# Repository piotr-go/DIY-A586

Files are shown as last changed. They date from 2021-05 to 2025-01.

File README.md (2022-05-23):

# DIY-A586 by Piotr Gozdur <piotr_go>
© COMMERCIAL USE NOT ALLOWED!

- [DIY-A586 v1.6](./v1.6)
(8MB RAM)
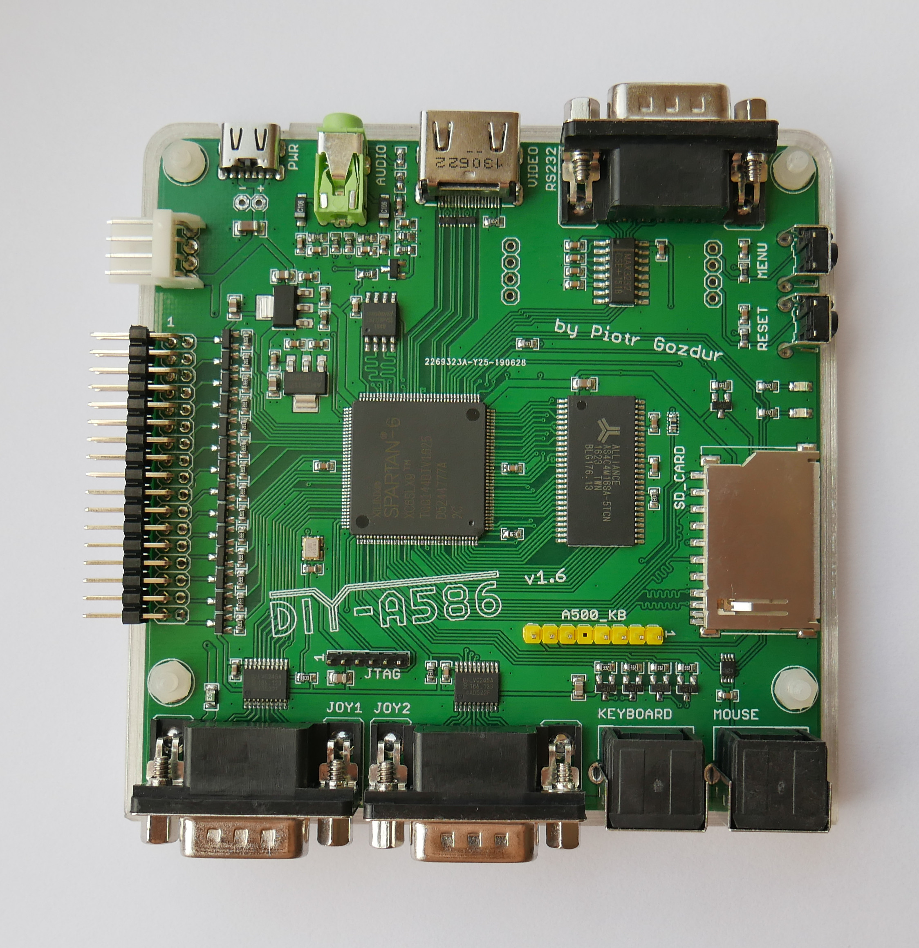
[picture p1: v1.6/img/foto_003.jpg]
DIY-A586 v1.6


- [DIY-A586 v1.9](./v1.9)
(32MB RAM)
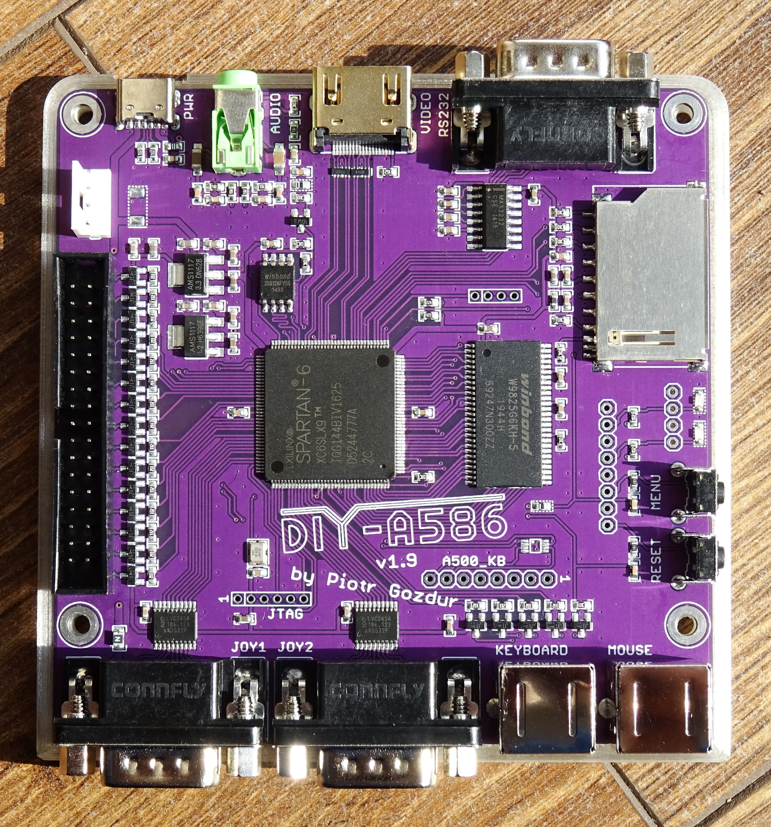
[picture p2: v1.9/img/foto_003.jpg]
DIY-A586 v1.9


<br><b>If you like my projects, you can support me with a donation.&nbsp;&nbsp;</b>

<b>&nbsp;&nbsp;Thank you.</b><br>

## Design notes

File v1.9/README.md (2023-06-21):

# DIY-A586 v1.9 by Piotr Gozdur <piotr_go>
© COMMERCIAL USE NOT ALLOWED!

<!-- no toc -->
- [Board](#board)
- [Schematic](#schematic)
- [Main menu](#main-menu)
- [Available cores](#available-cores)
- [Initial flashing of the firmware](#initial-flashing-of-the-firmware)
  - [Using CH341A 24 25 Series EEPROM Flasher](#using-ch341a-24-25-series-eeprom-flasher)
  - [detailed example of how to flash](#detailed-example-of-how-to-flash)
- [Links](#links)

## Board
[Gerber files](pcb/v1.9/gerbers.tar.gz) and [main core](main/MAIN%20v0.4.4a.tar.gz) included.

DIY-A586 top
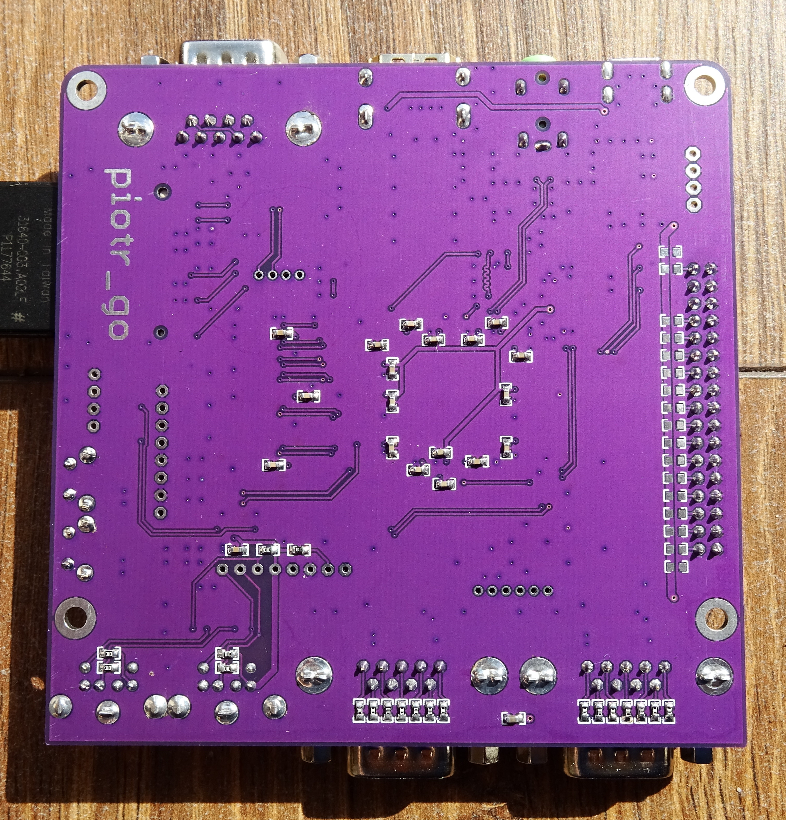
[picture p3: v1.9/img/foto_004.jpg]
DIY-A586 bottom


## Schematic
Schematic

## Main menu
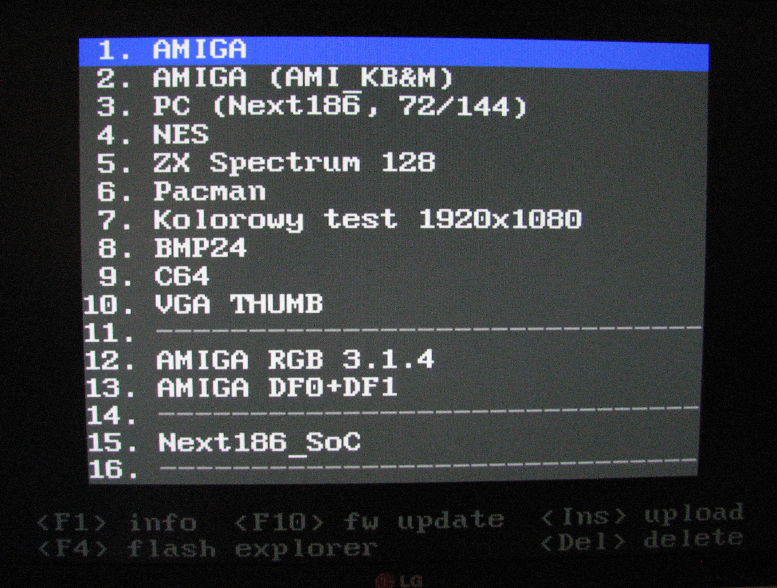
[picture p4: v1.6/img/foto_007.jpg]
main-menu


## Available cores
* Amiga (Minimig)
* PC 8088
* NES
* RISC-V

## Initial flashing of the firmware

### Using CH341A 24 25 Series EEPROM Flasher

This shows the initial flashing with the CH341A programmer on Ubuntu using the [flashrom tool](https://manpages.ubuntu.com/manpages/focal/man8/flashrom.8.html).

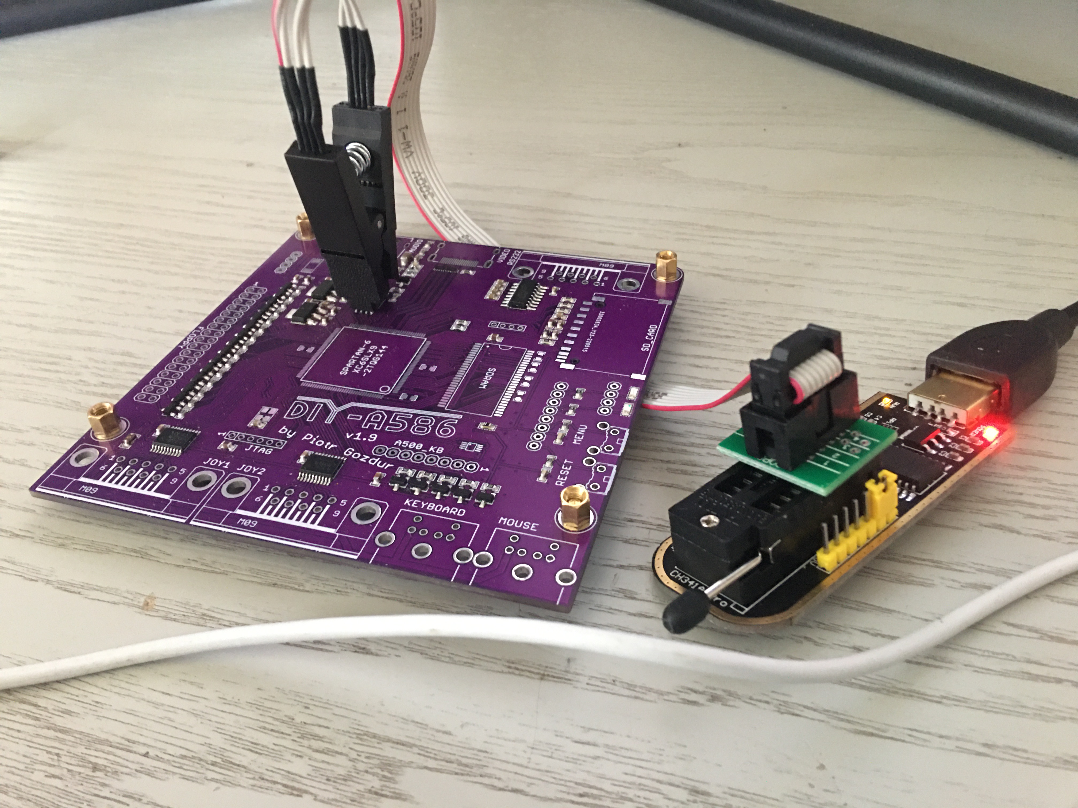
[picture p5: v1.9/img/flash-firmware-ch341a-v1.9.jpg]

flashrom has the weird behaviour that the bin file must have the exact size of the flash rom. This can be fixed with the following workaround:

* read empty flash and write to local .bin file: ```sudo flashrom --programmer ch341a_spi -r example.bin```
* copy main.bin into example.bin with: ```dd if=main.bin of=example.bin conv=notrunc```
* check result: ```vbindiff main.bin example.bin```

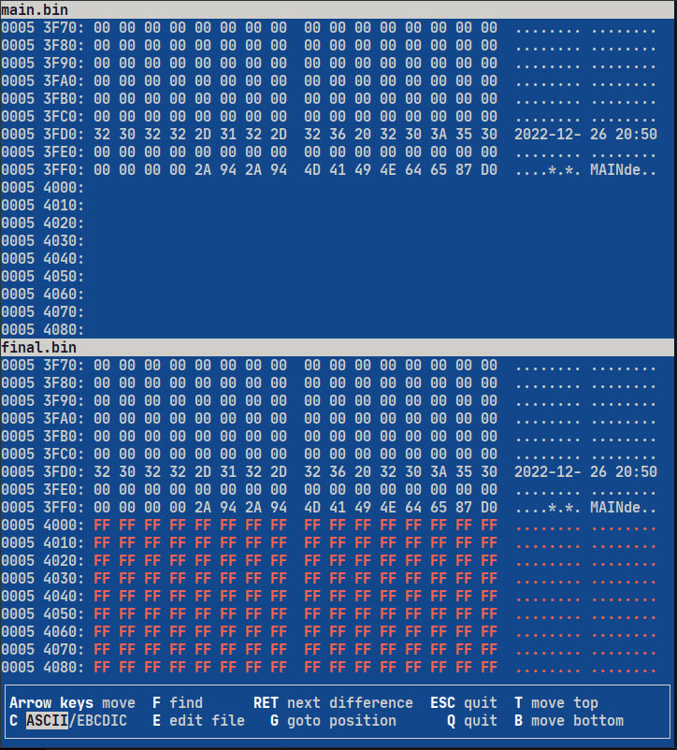
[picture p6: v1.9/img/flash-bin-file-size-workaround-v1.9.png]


* now you have a bin file with correct size to flash: ```sudo flashrom --programmer ch341a_spi -w example.bin```
* you're done ;o)

> Change the example filenames above to your needs respectively to current main.bin version!

### detailed example of how to flash

```bash
# read the contents of current soldered empty flash memory
csg@csg-deskmini-300:~/git/DIY-A586/v1.9/main$ sudo flashrom --programmer ch341a_spi -r empty.bin
[sudo] Passwort für csg: 
flashrom v1.2 on Linux 5.15.0-73-generic (x86_64)
flashrom is free software, get the source code at https://flashrom.org

Using clock_gettime for delay loops (clk_id: 1, resolution: 1ns).
Found Winbond flash chip "W25Q128.V" (16384 kB, SPI) on ch341a_spi.
Reading flash... done.

# make copy of empty rom file
csg@csg-deskmini-300:~/git/DIY-A586/v1.9/main$ cp empty.bin final.bin

# copy main.bin into final.bin rom file
csg@csg-deskmini-300:~/git/DIY-A586/v1.9/main$ dd if=main.bin of=final.bin conv=notrunc
672+0 Datensätze ein
672+0 Datensätze aus
344064 Bytes (344 kB, 336 KiB) kopiert, 0,00142343 s, 242 MB/s

# use vbindiff to show result of dd command. see screenshot above.
csg@csg-deskmini-300:~/git/DIY-A586/v1.9/main$ vbindiff main.bin final.bin 
VBinDiff 3.0_beta5, Copyright 1995-2017 Christopher J. Madsen
VBinDiff comes with ABSOLUTELY NO WARRANTY; for details type 'vbindiff -L'.

# write final.bin file to rom
csg@csg-deskmini-300:~/git/DIY-A586/v1.9/main$ sudo flashrom --programmer ch341a_spi -w final.bin 
flashrom v1.2 on Linux 5.15.0-73-generic (x86_64)
flashrom is free software, get the source code at https://flashrom.org

Using clock_gettime for delay loops (clk_id: 1, resolution: 1ns).
Found Winbond flash chip "W25Q128.V" (16384 kB, SPI) on ch341a_spi.
Reading old flash chip contents... done.
Erasing and writing flash chip... Erase/write done.
Verifying flash... VERIFIED.

# optional: verify again if wanted.
csg@csg-deskmini-300:~/git/DIY-A586/v1.9/main$ sudo flashrom --programmer ch341a_spi -v final.bin 
flashrom v1.2 on Linux 5.15.0-73-generic (x86_64)
flashrom is free software, get the source code at https://flashrom.org

Using clock_gettime for delay loops (clk_id: 1, resolution: 1ns).
Found Winbond flash chip "W25Q128.V" (16384 kB, SPI) on ch341a_spi.
Verifying flash... VERIFIED.
```

## Links
* https://www.elektroda.pl/rtvforum/topic3891155.html
* https://youtu.be/KzVHhvZciVI

<br><b>If you like my projects, you can support me with a donation.&nbsp;&nbsp;</b>

<b>&nbsp;&nbsp;Thank you.</b><br>

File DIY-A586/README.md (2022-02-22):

# DIY-A586 by Piotr Gozdur <piotr_go>

- [Board](#board)
- [Schematic](#schematic)
- [Menu of main core](#menu-of-main-core)
- [Available cores](#available-cores)
- [Running Minimig core](#running-minimig-core)
- [Initial flashing of the firmware](#initial-flashing-of-the-firmware)
  - [Using CH341A 24 25 Series EEPROM Flasher](#using-ch341a-24-25-series-eeprom-flasher)
- [Gotek Floppy Emulator](#gotek-floppy-emulator)
- [Floppy splitter](#floppy-splitter)
  - [Floppy splitter board](#floppy-splitter-board)
  - [Floppy splitter schematic](#floppy-splitter-schematic)
  - [Programming the PIC16F15313](#programming-the-pic16f15313)
  - [Pinout PIC16F15313](#pinout-diagram-pic16f15313)
  - [Pinout PICkit3](#pinout-pickit3)
- [Links](#links)

## Board

[Gerber files](pcb/v1.6/gerbers.tar.gz) and [main core](main/MAIN%20v0.4.3.tar.gz) included.

> © DIY-A586 by Piotr Gozdur. COMMERCIAL USE NOT ALLOWED!

DIY-A586 top
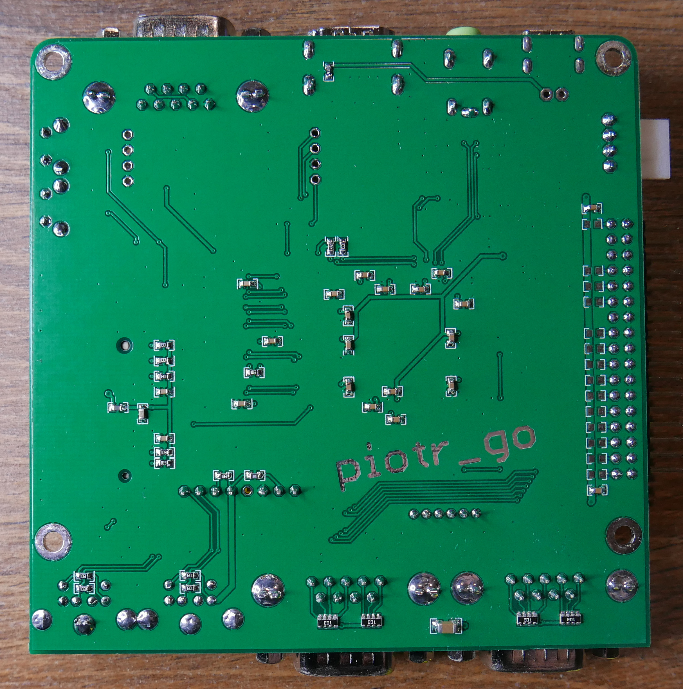
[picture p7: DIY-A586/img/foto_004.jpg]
DIY-A586 bottom


## Schematic
Schematic

## Menu of main core
Main core menu

## Available cores

* Amiga (Minimig)
* NES
* Next186 SoC PC
* RISC-V
* Sinclair Spectrum

## Running Minimig core
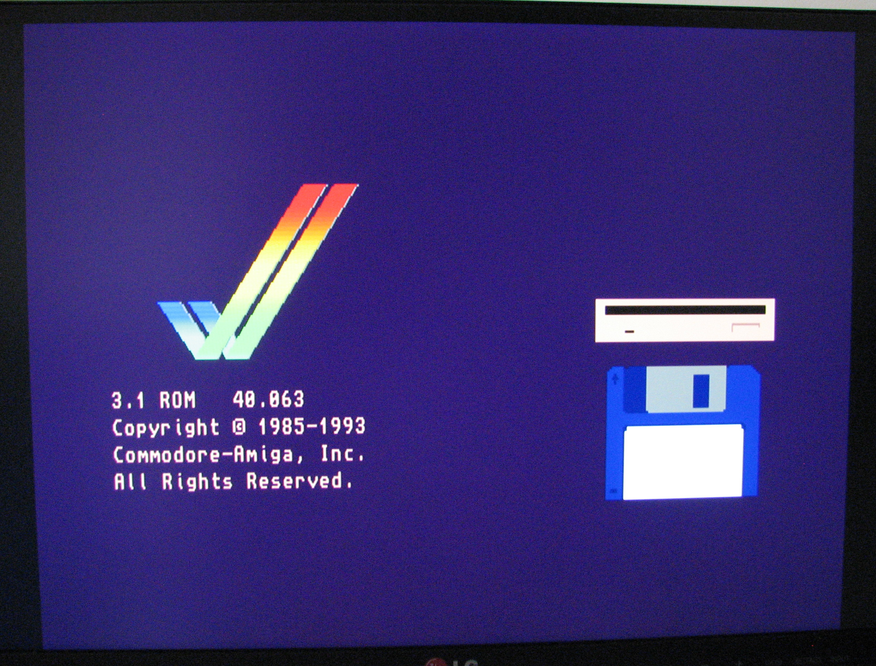
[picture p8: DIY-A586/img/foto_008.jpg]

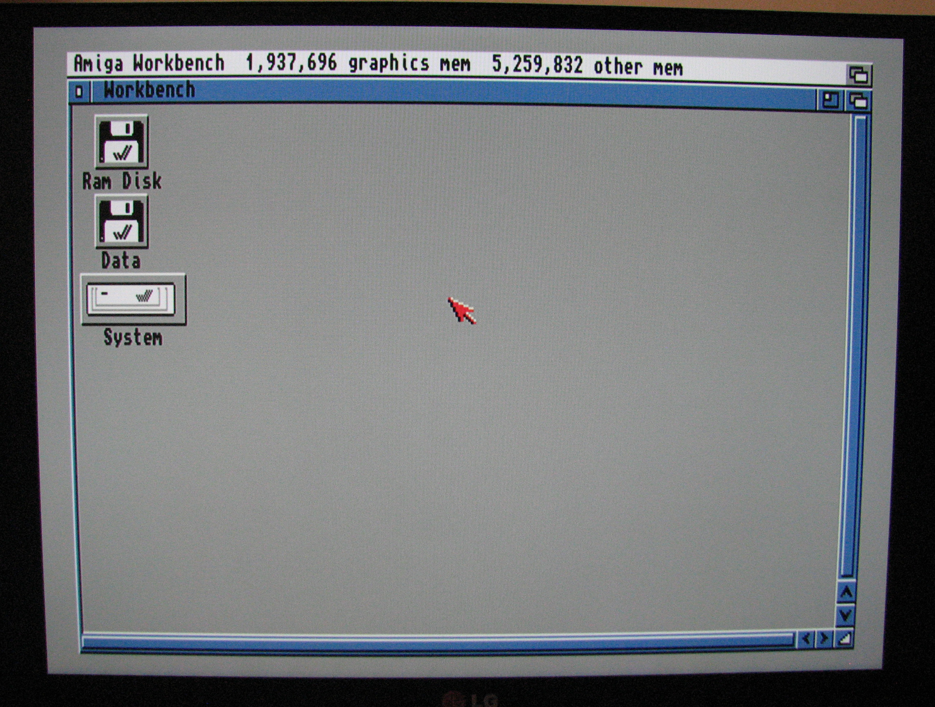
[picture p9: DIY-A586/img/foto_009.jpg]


## Initial flashing of the firmware

### Using CH341A 24 25 Series EEPROM Flasher

This shows the initial flashing with the CH341A programmer on Ubuntu using the [flashrom tool](https://manpages.ubuntu.com/manpages/focal/man8/flashrom.8.html).

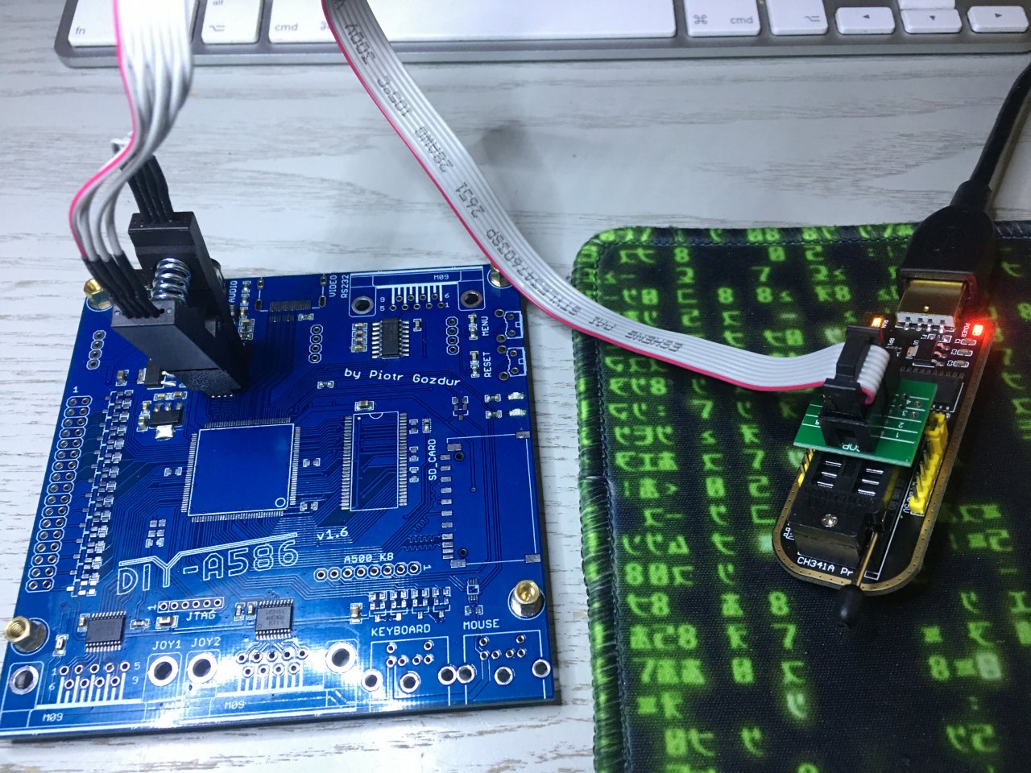
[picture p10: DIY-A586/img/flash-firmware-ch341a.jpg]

flashrom has the weird behaviour that the bin file must have the exact size of the flash rom. This can be fixed with the following workaround:

* read empty flash and write to local .bin file: ```sudo flashrom --programmer ch341a_spi -r example.bin```
* copy main.bin into example.bin with: ```dd if=main.bin of=example.bin conv=notrunc```
* check result: ```vbindiff main.bin example.bin```

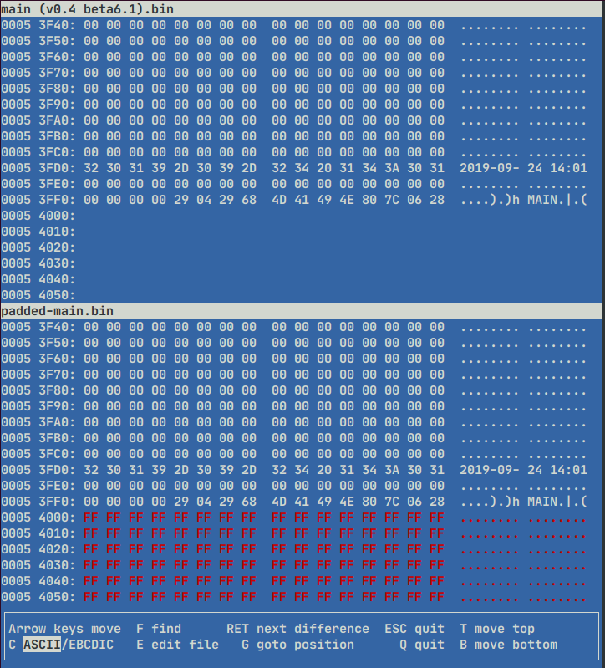
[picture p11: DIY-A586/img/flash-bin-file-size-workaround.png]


* now you have a bin file with correct size to flash: ```sudo flashrom --programmer ch341a_spi -w example.bin```
* you're done ;o)

> Change the example filenames above to your needs respectively to current main.bin version!

## Gotek Floppy Emulator

If you are using a Gotek drive with FlashFloppy, don't copy files **HXCSDFE.CFG** and **AUTOBOOT.HFE** to the USB stick. The FlashFloppy/HxC File Selector will not work with DIY-A586. Copy only the **.adf** files to the USB stick and select the files with buttons or the rotary knob.

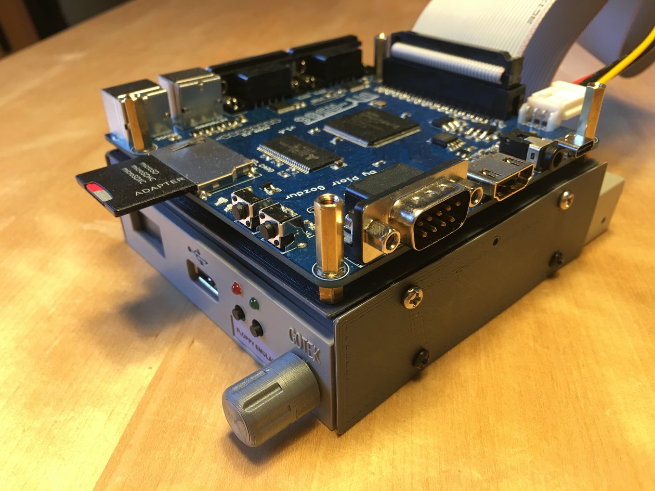
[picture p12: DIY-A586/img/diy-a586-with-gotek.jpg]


## Floppy splitter
With an attached floppy splitter you can attach up to two floppy drives to the DIY-A586 used by the [Amiga Minimig core](cores/amiga/minimig/v0.3/amiga_v0.3_src.tar.gz).

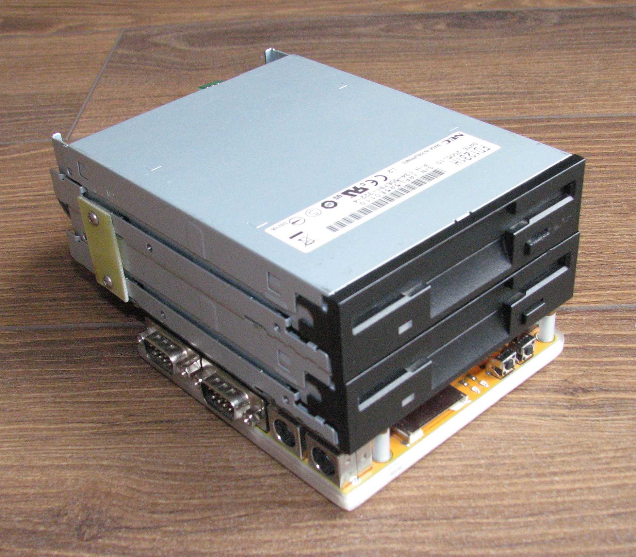
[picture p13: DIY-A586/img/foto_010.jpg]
attached two floppy drives


### Floppy splitter board

Gerber files and PIC16F15313 firmware [included](cores/amiga/minimig/amiga_floppy_splitter%20v0.1%20by%20piotr_go.tar.gz).

> © Floppy Splitter by Piotr Gozdur. COMMERCIAL USE NOT ALLOWED!

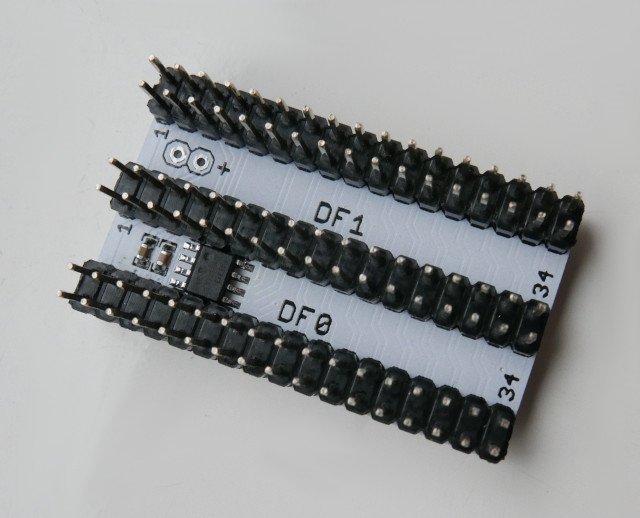
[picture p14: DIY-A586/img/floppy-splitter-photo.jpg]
floppy splitter board


### Floppy splitter schematic

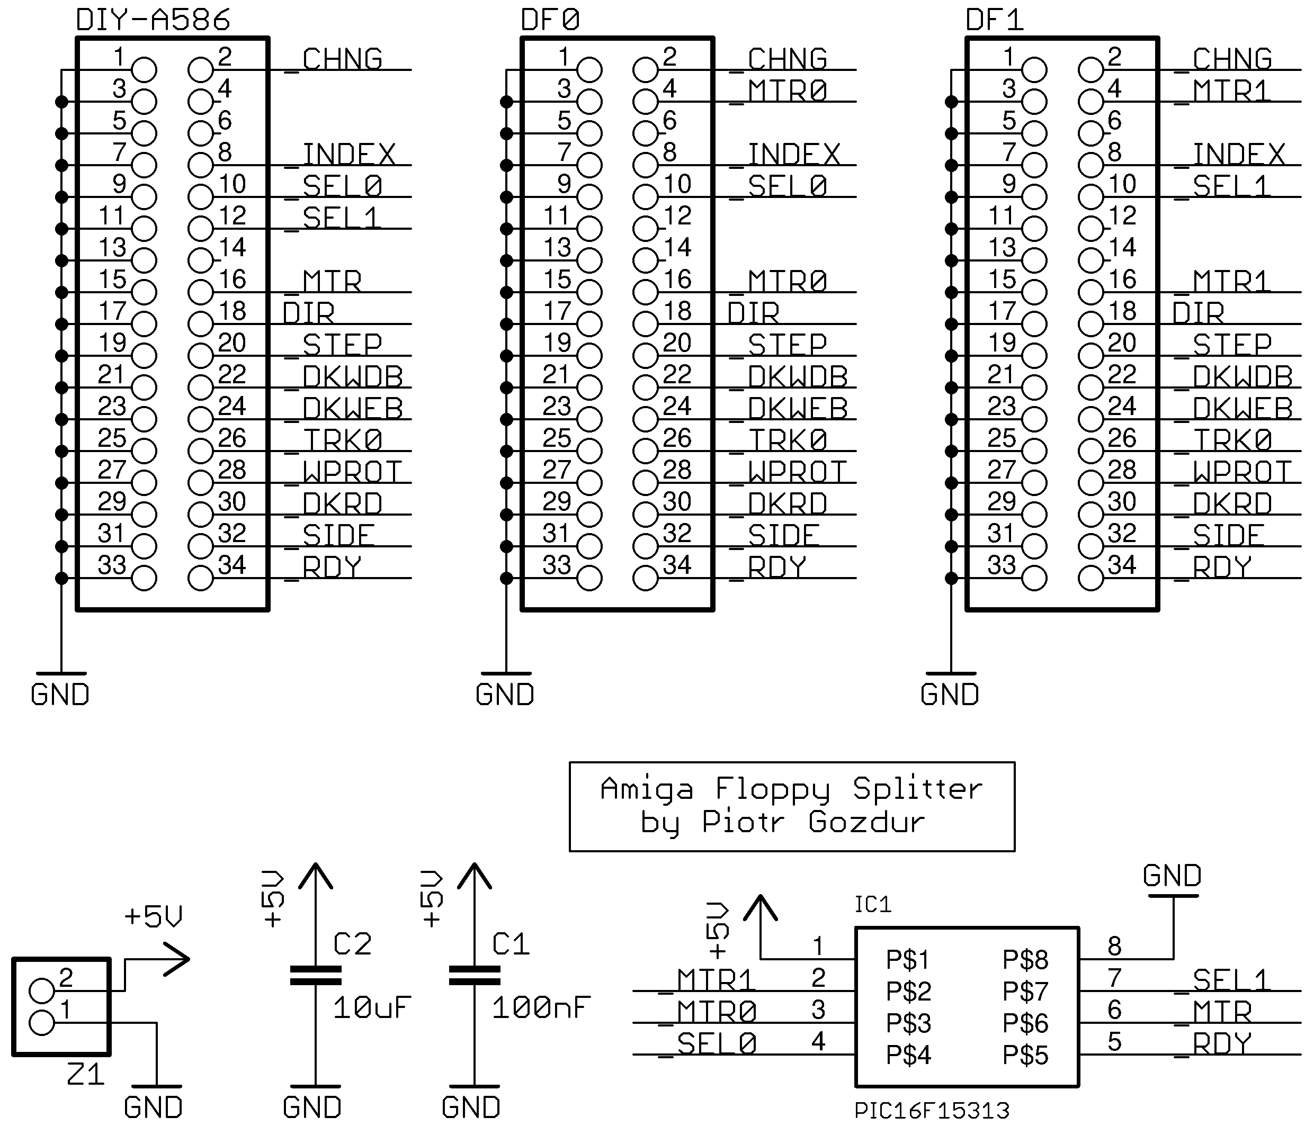
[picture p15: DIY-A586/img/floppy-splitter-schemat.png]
schematic of floppy splitter


### Programming the PIC16F15313

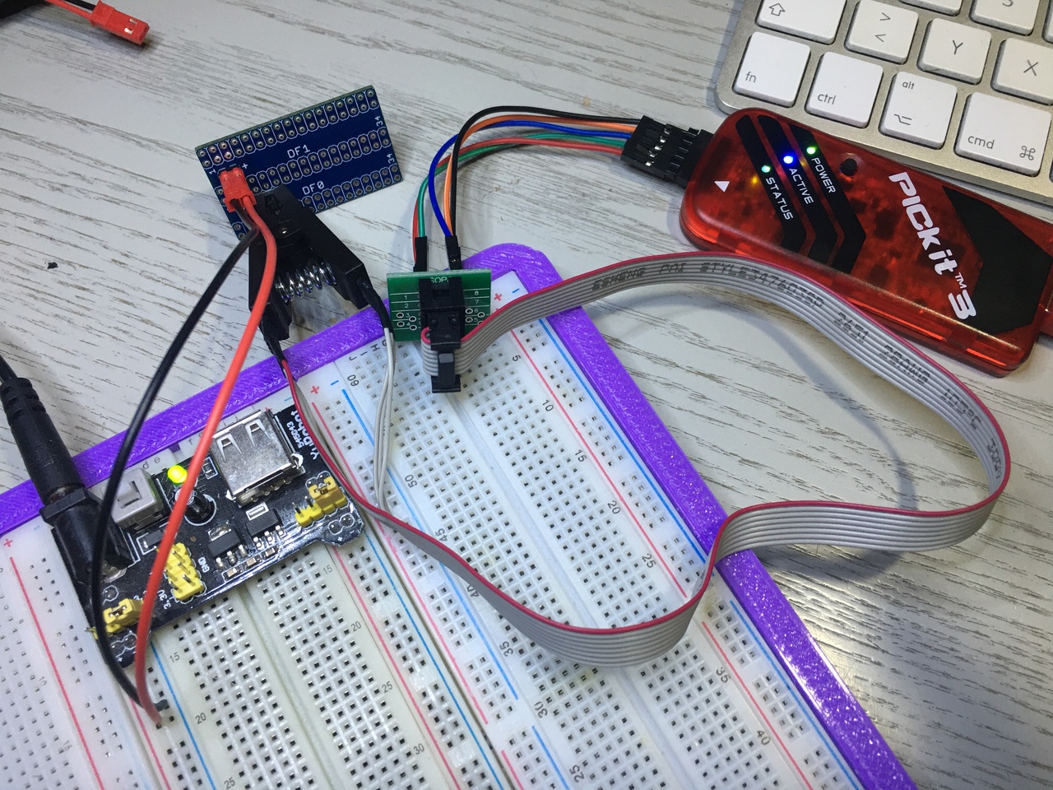
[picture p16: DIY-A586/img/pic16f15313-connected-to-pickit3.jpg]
pick16f15313 connected to pickit3


Connect the PIC16F15313 to an PICkit3 programmer. The PIC16F15313 needs additional power (it didn't work for me without it).

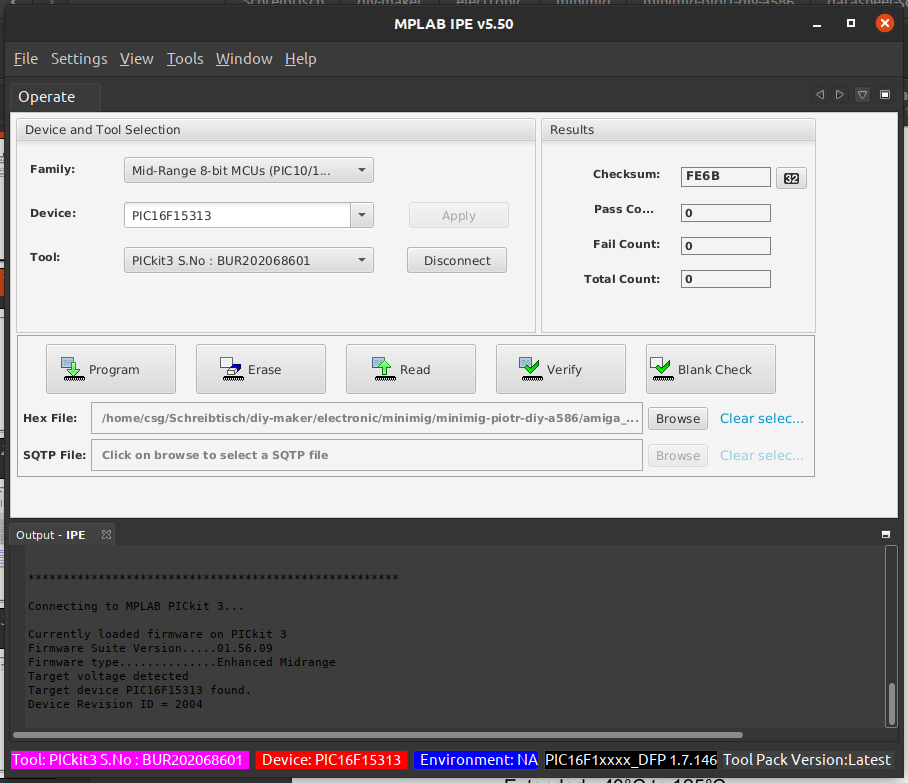
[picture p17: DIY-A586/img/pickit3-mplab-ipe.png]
MPLAB IPE


Using MPLAB IPE to programm the HEX file of the floppy-splitter. See settings in screenshot. Select the hex file and press "Program".

### Pinout diagram PIC16F15313

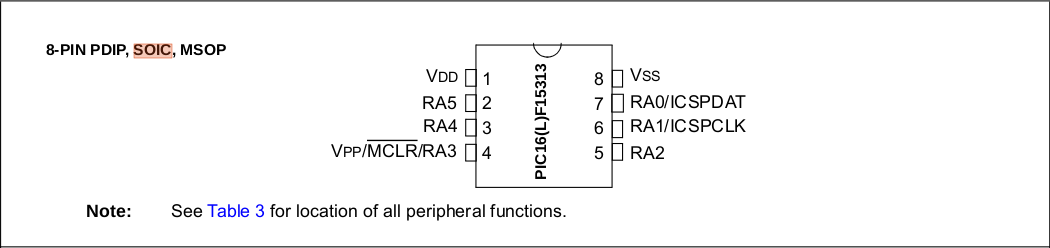
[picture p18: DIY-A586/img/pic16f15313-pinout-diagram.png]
pick16f15313 pinout diagram


### Pinout PICkit3

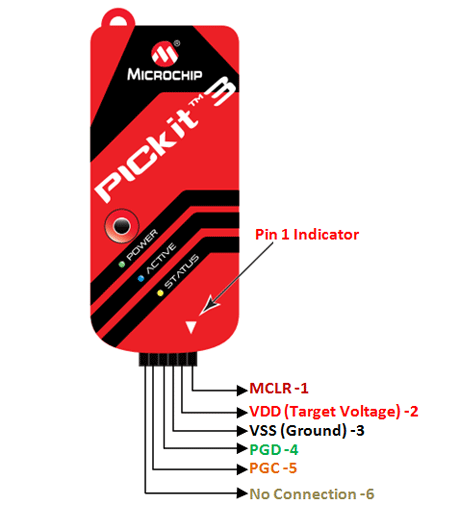
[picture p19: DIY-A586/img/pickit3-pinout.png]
pickit3 pinout


## Links
* https://www.elektroda.com/rtvforum/topic3598849.html or\
  https://www.elektroda.pl/rtvforum/topic3598849.html or\
  https://www.elektroda.de/rtvforum/topic3598849.html
* https://www.youtube.com/watch?v=OAxe3ryDPwQ&list=PLbiryfyA62EBfDKSVf1hBP-nj-KQiV575

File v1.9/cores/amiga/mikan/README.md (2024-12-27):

# "mikan" Amiga core by Piotr Gozdur

- mikan_v0.1.9
  - Amiga mouse support
  - Amiga keyboard support (mikan_k500)

- mikan_v0.1.8
  - new hotkeys

- mikan_v0.1.7
  - faster SD
  - bitplanes fix
  - audio interrupt fix, again

- mikan_v0.1.6
  - new floppy read

- mikan_v0.1.5
  - PAULA reset fix
  - collision fix

- mikan_v0.1.4
  - added automatic floppy switcher
  - LED fix

- mikan_v0.1.3
  - Sprite fix

- mikan_v0.1.2
  - new audio state machine
  - Copper timing fix
  - image cropping fix

- mikan_v0.1.1
  - CIA speed fix
  - CIA timer fix
  - audio interrupt fix

- mikan_v0.1.0
  - initial release

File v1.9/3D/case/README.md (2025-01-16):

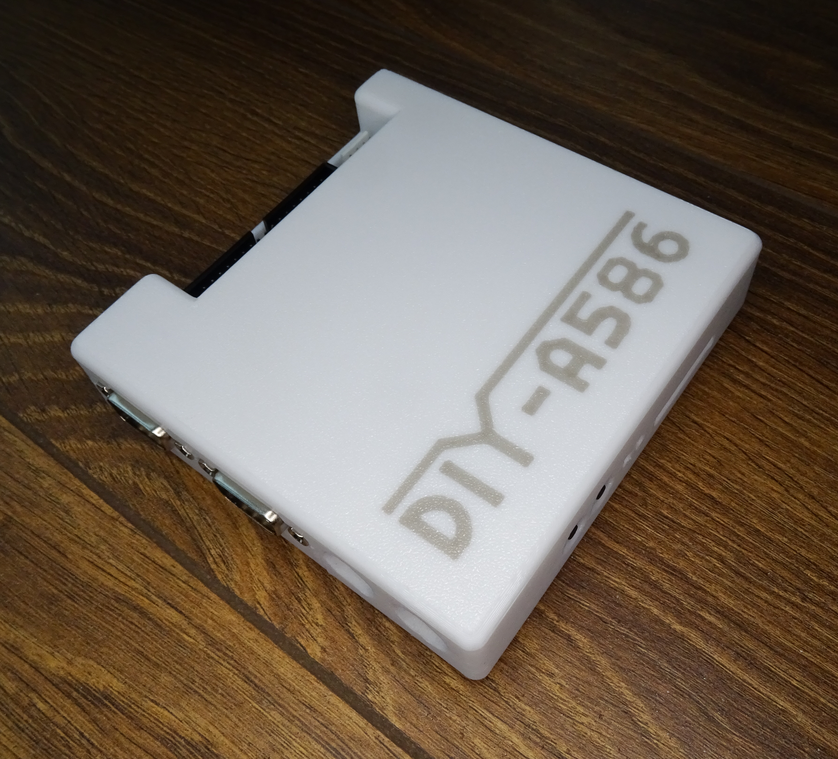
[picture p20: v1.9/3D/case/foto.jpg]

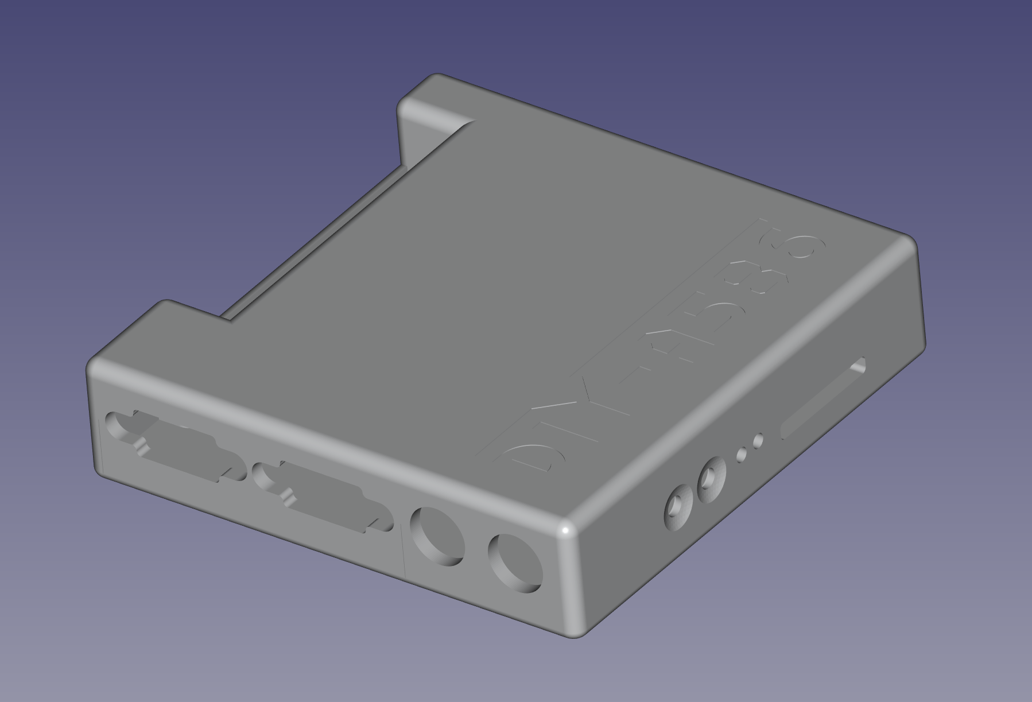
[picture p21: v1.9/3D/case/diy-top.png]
top

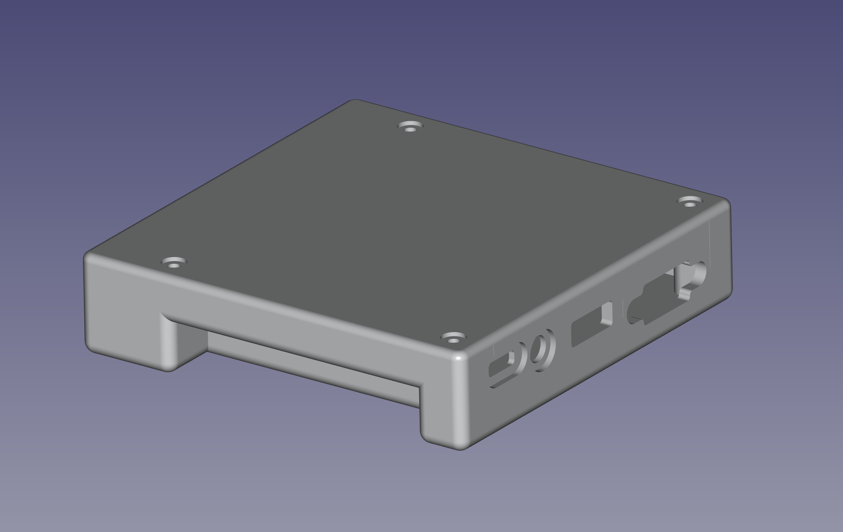
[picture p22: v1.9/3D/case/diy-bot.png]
bottom


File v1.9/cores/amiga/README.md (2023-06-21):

# Amiga core

Minimig core
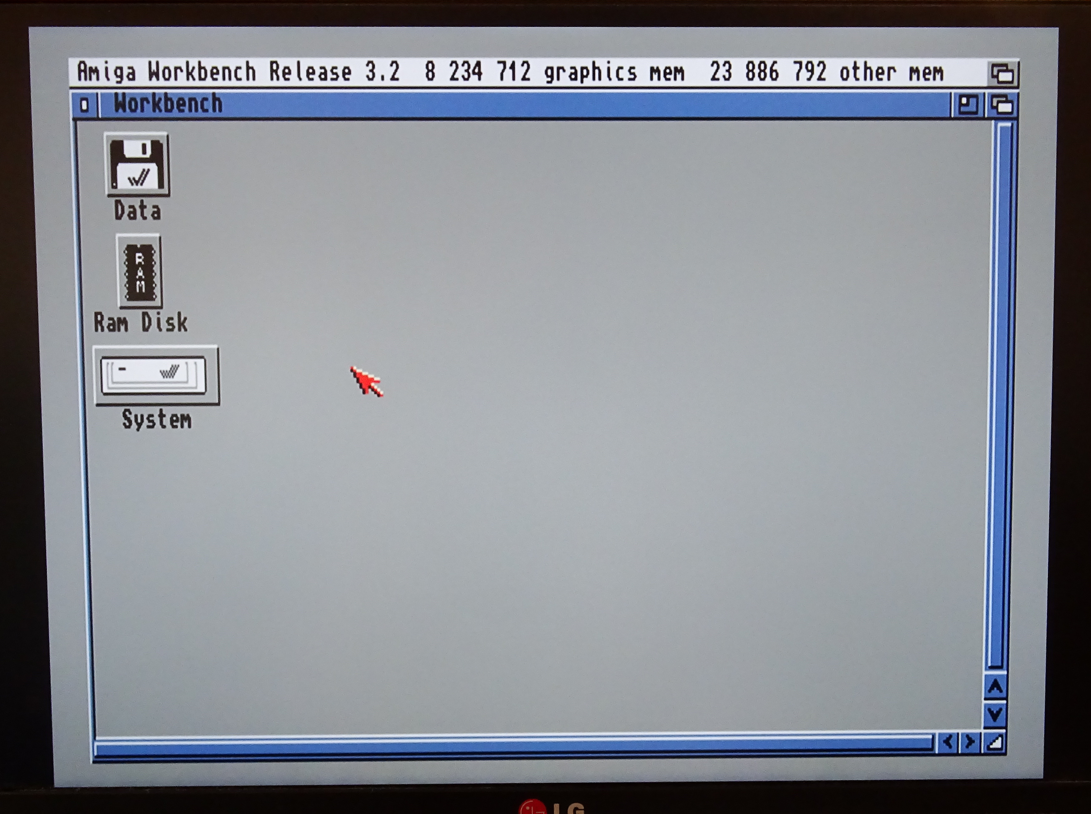
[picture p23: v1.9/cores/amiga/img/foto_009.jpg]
Minimig core


<!-- no toc -->
- [Gotek Floppy Emulator](#gotek-floppy-emulator)
- [SD Card Amiga OS preparation howto](#sd-card-amiga-os-preparation-howto)
  - [Creating a HDF harddisk image file](#creating-a-hdf-harddisk-image-file)
  - [Setup UAE and HDToolBox](#setup-uae-and-hdtoolbox)
  - [Reboot after partitioning, formatting partitions, install Amiga OS](#reboot-after-partitioning-formatting-partitions-install-amiga-os)
  - [Writing HDF file to SD Card](#writing-hdf-file-to-sd-card)
  - [Boot DIY-A586 with SD Card](#boot-diy-a586-with-sd-card)

## Gotek Floppy Emulator
Copy only the **.adf** files to the USB stick and select the files with buttons or the rotary knob.
Minimig core

## SD Card Amiga OS preparation howto

Following there is a rough description how to setup a SD Card with Amiga OS for DIY-A586  
using the amiga core with patched kickstart rom.  
For this you need a little help from [WinUAE](https://www.winuae.net/) or [FS-UAE](https://fs-uae.net/) installed on Win, macOS or Linux.

### Creating a HDF harddisk image file

To start you need an Amiga HDF file. This can be created e.g. under [FS-UAE](https://fs-uae.net/) with the ```HDF Disk Image Creator``` tool.  

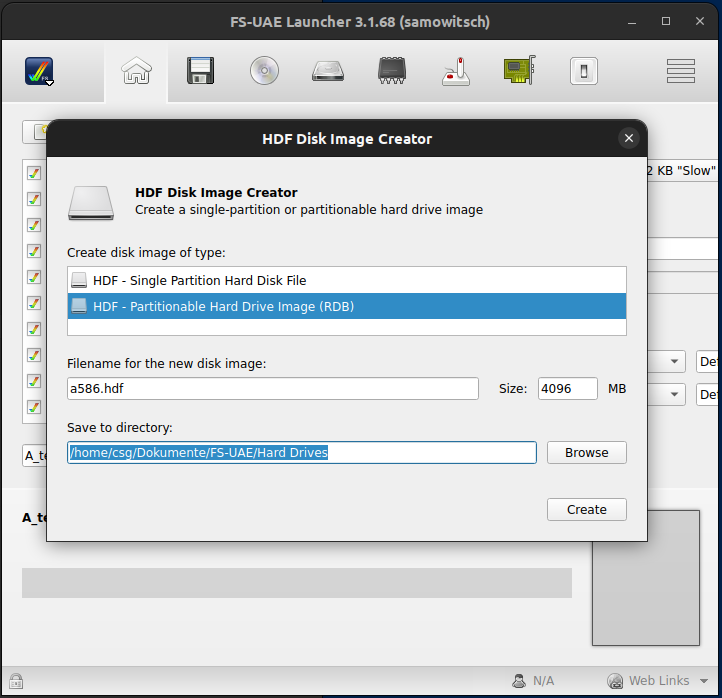
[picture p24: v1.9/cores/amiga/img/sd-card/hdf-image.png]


Choose ```Partitionable Hard Drive Image (RDB)```. See screenshot. Setup the rest to your needs. 4096 MB is a good choice.  
> If you want more you have to keep the max partition size of used Amiga filesystem in mind.

### Setup UAE and HDToolBox

Setup your amiga emulator of choice using needed Amiga OS install discs (ADF) and the new created HDF file.  
Boot up UAE with Workbench install disc. Open the Tools window located on install disk. Select ```HDToolBox``` icon.  
Then got to menu ```Icon/Information```. In the following window click ```SCSI_DEVICE_NAME``` and change ```scsi.device``` to ```uaehf.device```.

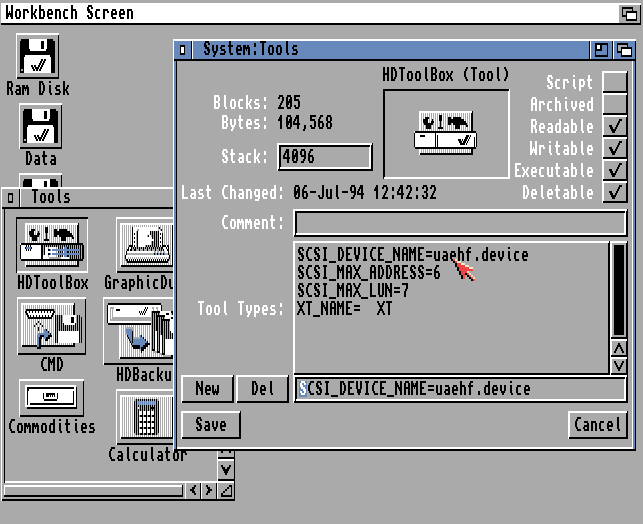
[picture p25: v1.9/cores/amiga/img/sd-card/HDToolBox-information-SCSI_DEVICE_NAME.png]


Save and open ```HDToolBox``` again. You should see now a harddrive in the list.  
> If not you have to use ```Change Drive Type```. Hard to describe just look here: [Setup Amiga Hard Drive using FS-UAE](https://www.youtube.com/watch?v=88jxTQo4uhs)

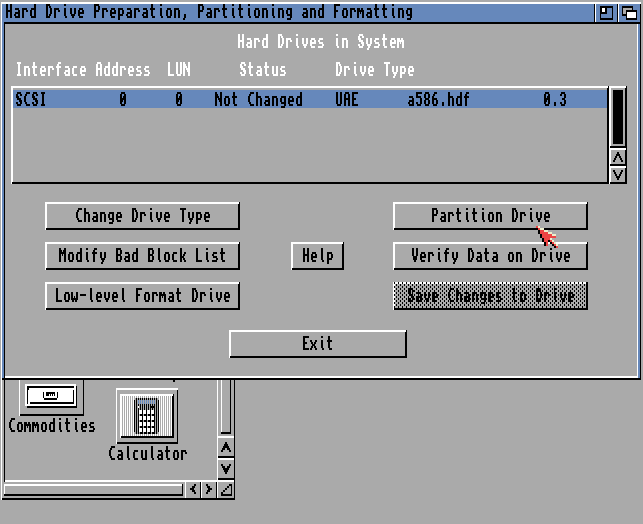
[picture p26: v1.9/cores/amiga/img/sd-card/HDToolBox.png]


Click on ```Partition Drive```. In the following window just partition the harddrive to your needs.  
For example there are three partitions: ```System DH0 (0.5GB)```, ```Work DH1 (1.8GB)``` and ```Data DH2 (1.7GB)```



> More detailed partitioning info see here: [Setup Amiga Hard Drive using FS-UAE](https://www.youtube.com/watch?v=88jxTQo4uhs)

If your partitioning is done press ```Save Changes to Drive```.

### Reboot after partitioning, formatting partitions, install Amiga OS

After partitioning reboot UAE. You should see now for example unformatted harddrives ```DH0:NDOS``` and so on.  
You can quick format each partition. Select partition icon and go to menu ```Icons/Format Disk...```  



Give it a proper name and press ```Quick Format```. If all partitions are formatted you can install Amiga OS  
from the install disks. Install additional software over shared folders or from other ADF/HDF drives.

### Writing HDF file to SD Card

If your HDF file is prepared write it with e.g. the ```Raspberry Pi Imager``` to SD Card.  



First step is to choose your operating system -> select ```own image```.  
Navigate to the folder where HDF file is located and switch filetype to ```All files```.  
Select HDF file, choose target SD Card and click write.

### Boot DIY-A586 with SD Card 

Insert now SD Card into DIY-A586. Needed patched kickstart e.g. ```KICK31SD.ROM``` must be available in onboard flash rom.  
Start amiga core with ```kickstart 3.1 + SD```.

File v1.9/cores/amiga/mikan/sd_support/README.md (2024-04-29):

# SD Card support for mikan core by Piotr Gozdur

Option 1:
  Whole card is single Amiga HD.
  Remove card MBR and create partitions with HDToolBox.

Option 2:
  1 card partition = 1 Amiga HD
  Card must have MBR. Primary partitions only.
  Choose partition type "F0" for Amiga RDB.
  Example: If your card have 3 paritions [fat12, "F0", fat32] disk order on Amiga side will be ["F0", fat12, fat32] (unit 0, 1, 2).
  Warning: Do not touch you FAT disks with HDToolBox.
  For FAT support install fat95.

	FileSystem     = l:fat95
	Device         = scsi.device
	Unit           = 2 /* change unit number here */
	Flags          = 0
	LowCyl         = 0
	HighCyl        = 0
	Surfaces       = 1
	BlocksPerTrack = 1
	BlockSize      = 512
	Buffers        = 20
	BufMemType     = 1
	BootPri        = 0
	Stacksize      = 4096
	Priority       = 0
	GlobVec        = -1
	DosType        = 0x46415401

Changes:

- v0.10.1
  - write fix
  - added card reset and retry when error

- v0.10
  - speed
  - bug fixes

- v0.9.1
  - PDS partition support

- v0.9
  - multiple HD support
  - PFS3 support
  - ROM patching not needed

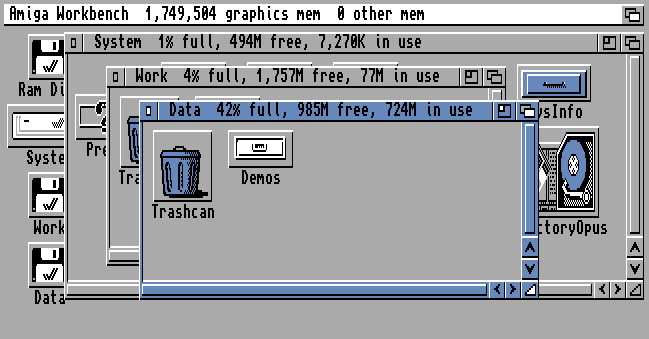
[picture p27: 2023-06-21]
v1.9/cores/amiga/img/sd-card/workbench-drives.png

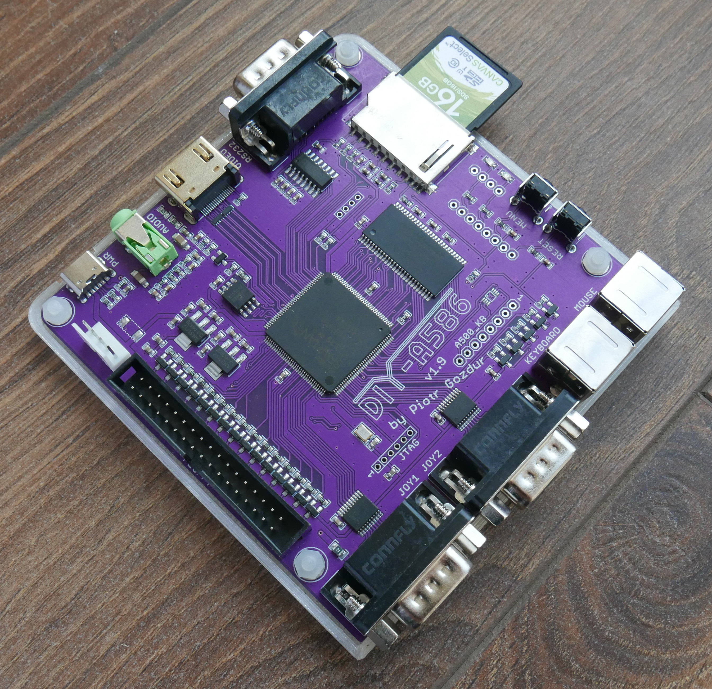
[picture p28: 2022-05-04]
v1.9/img/foto_002.jpg

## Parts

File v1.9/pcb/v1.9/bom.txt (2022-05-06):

Partlist exported from diy_a586.sch at 06.05.2022 12:09

Qty Value                      Package       Parts
1   PINHEAD-2X17               2X17          FLOPPY
1   PINHEAD-1X4                PINHEAD-1X4   Z1
1   PINHEAD-1X4-2.0mm          PH20-1X4      Z4
1   PINHEAD-1X4                PINHEAD-1X4   Z2
1   PINHEAD-1X6-2.0mm          PH20-1X6      JTAG
2   PINHEAD-1X8                PINHEAD-1X8   Z6
2   switch                                   S1, S2
1   USB-C                      6-pin         USB-C
1   polymer fuse 0.75A         0603          F3
1   polymer fuse 0.75A         0805          F1
1   SPX1117-1.2V               SOT223        IC10
3   100                        0603          R32, R53, R54
43  100nF                      0603          C1, C2, C3, C4, C5, C6, C7, C9, C10, C11, C12, C14, C15, C20, C26, C27, C28, C29, C31, C32, C33, C34, C36, C37, C39, C40, C41, C42, C43, C44, C45, C46, C47, C48, C49, C50, C55, C56, C57, C58, C60, C62, C63
31  10k                        0603          R1, R2, R3, R4, R5, R33, R34, R35, R49, R58, R59, R60, R61, R62, R63, R65, R66, R67, R68, R69, R70, R71, R72, R73, R74, R75, R76, R77, R78, R79, R80
7   10nF                       0603          C16, C17, C18, C19, C52, C54, C59
2   10uF                       1206          C25, C30
11  10uF                       0603          C8, C13, C21, C22, C23, C24, C35, C38, C51, C53, C61
1   18.432MHz_GENERATOR_3.3V   3.2x2.5mm     IC6
2   1N4148                     0603          D1, D2
3   1k                         0603          R8, R51, R52
1   SPX1117-3.3V               SOT223        IC4
19  3k3                        0603          R12, R15, R16, R17, R18, R26, R36, R37, R38, R39, R40, R41, R42, R43, R44, R45, R46, R47, R48
2   4k7                        0603          R10, R57
5   560                        0603          R27, R29, R30, R31, R64
2   5k1                        0603          R50, R55
1   74HCT2G125                 DCU-8         IC9
2   74LVC245                   TSSOP20       IC2, IC3
1   BC847B                     SOT23         T20
20  BSS123/BSS138              SOT23         T1, T2, T3, T4, T5, T6, T7, T8, T9, T10, T11, T12, T13, T14, T15, T16, T17, T18, T19, T21
3   DB9M                       DB9M          JOY1, JOY2, RS232
1   GREEN                      LED0805       LED2
1   HDMI                       HDMI          VIDEO
1   JACK                       JACK          AUDIO
1   MAX3232CSE                 SO16          IC5
2   MINI-DIN6                  MINI-DIN6     KEYBOARD, MOUSE
1   PTVS5V0P1UP                SOD128        D3
2   PUSB3FR4Z                                E1, E2
1   RED                        LED0805       LED1
1   SD                         SD-SHORT      SD_CARD
1   W25Q128JVSIQ               SOIC-8        IC8
1   W9825G6KH-5                TSOP54        IC7
1   XC6SLX9-2TQG144            TQFP144       IC1
1   ferrite bead               0603          F2
15  np                         0603          R6, R7, R9, R11, R13, R14, R19, R20, R21, R22, R23, R24, R25, R28, R56

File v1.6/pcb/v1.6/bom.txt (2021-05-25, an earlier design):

Part	Value	Package

A500_KB		PINHEAD-1X8
AUDIO	JACK	JACK-S
C1	100nF	0603
C2	100nF	0603
C3	100nF	0603
C4	100nF	0603
C5	100nF	0603
C6	100nF	0603
C7	100nF	0603
C8	10uF	0805
C9	100nF	0603
C10	100nF	0603
C11	100nF	0603
C12	100nF	0603
C13	10uF	0603
C14	100nF	0603
C15	100nF	0603
C16	10nF	0603
C17	10nF	0603
C18	10nF	0603
C19	10nF	0603
C20	100nF	0603
C21	10uF	0805
C22	10uF	0805
C23	10uF	1206
C24	10uF	1206
C25	10uF	CT3216
C26	100nF	0603
C27	100nF	0603
C28	100nF	0603
C29	100nF	0603
C30	10uF	CT3216
C31	100nF	0603
C32	100nF	0603
C33	100nF	0603
C34	100nF	0603
C35	10uF	0805
C36	100nF	0603
C37	100nF	0603
C38	10uF	0603
C39	100nF	0603
C40	100nF	0603
C41	100nF	0603
C42	100nF	0603
C43	100nF	0603
C44	100nF	0603
C45	100nF	0603
C46	100nF	0603
C47	100nF	0603
C48	100nF	0603
C49	100nF	0603
C50	100nF	0603
C51	10uF	0805
C52	100nF	0603
C53	10uF	0805
C54	100nF	0603
C55	1uF	0603
C56	100nF	0603
C57	100nF	0603
C58	100nF	0603
C59	10nF	0603
C60	100nF	0603
D1	1N4148	D0603
D2	1N4148	D0603
E1	PUSB3FR4Z	ESD2
E2	PUSB3FR4Z	ESD2
F1	0.75A	0805
F2	ferrite bead	0603
F3	0.75A	0603
FLOPPY		2X17
H1		3,2-PAD
H2		3,2-PAD
H3		3,2-PAD
H4		3,2-PAD
IC1	XC6SLX9-2TQG144	TQFP144
IC2	74LVC245	TSSOP20
IC3	74LVC245	TSSOP20
IC4	3.3V	SOT223
IC5	MAX3232CSE	SO16
IC6	16MHz_GENERATOR_3.3V_3.2x2.5mm	GENERATOR-SMD-3.2X2.5
IC7	AS4C4M16SA-5TCN	TSOP54
IC8	W25Q128JVSIQ	SPI_FLASH
IC9	74HCT2G125	DCU-8
IC10	1.2V	SOT223
JOY1	DB9M	DB9M
JOY2	DB9M	DB9M
JTAG		PH20-1X6
KEYBOARD	MINI-DIN6	MINI-DIN6
LED1		SML0805
LED2		SML0805
MOUSE	MINI-DIN6	MINI-DIN6
R1	10k	0603
R2	10k	0603
R3	10k	0603
R4	10k	0603
R5	10k	0603
R6		0603
R7		0603
R8	1k	0603
R9		0603
R10	4k7	0603
R11		0603
R13		0603
R14		0603
R15	3k3	0603
R16	3k3	0603
R17	3k3	0603
R18	3k3	0603
R19		0603
R20		0603
R21		0603
R22		0603
R23		0603
R24		0603
R25		0603
R26	3k3	0603
R27	560	0603
R28		0603
R29	560	0603
R30	560	0603
R31	560	0603
R32	100	0603
R33	10k	0603
R34	10k	0603
R35	10k	0603
R36	3k3	0603
R37	3k3	0603
R38	3k3	0603
R39	3k3	0603
R40	3k3	0603
R41	3k3	0603
R42	3k3	0603
R43	3k3	0603
R44	3k3	0603
R45	3k3	0603
R46	3k3	0603
R47	3k3	0603
R48	3k3	0603
R49	10k	0603
R50	10k	0603
R51	1k	0603
R52	1k	0603
R53	100	0603
R54	100	0603
R55	10k	0603
R56	10k	0603
R57	4k7	0603
R58	10k	0603
R59	10k	0603
R60	10k	0603
R61	10k	0603
R62	10k	0603
R63	10k	0603
R64	560	0603
R65	10k	0603
R66	10k	0603
RP1	10k	0603-ARC
RP2	10k	0603-ARC
RP3	10k	0603-ARC
RP4	10k	0603-ARC
RS232	DB9M	DB9M
S1		B3F-31XX
S2		B3F-31XX
SD_CARD	SD	SD-SHORT
T1	BSS123	SOT23_
T2	BSS123	SOT23_
T3	BSS123	SOT23_
T4	BSS123	SOT23_
T5	BSS123	SOT23_
T6	BSS123	SOT23_
T7	BSS123	SOT23_
T8	BSS123	SOT23_
T9	BSS123	SOT23_
T10	BSS123	SOT23_
T11	BSS123	SOT23_
T12	BSS123	SOT23_
T13	BSS123	SOT23_
T14	BSS123	SOT23_
T15	BSS123	SOT23_
T16	BSS123	SOT23_
T17	BSS123	SOT23_
T18	BSS123	SOT23_
T19	BSS123	SOT23_
T20	BC847	SOT23_
USB-C		USB-C-PWR
VIDEO		HDMI
Z1		PINHEAD-1X2B
Z2		PINHEAD-1X4B
Z3		PINHEAD-1X4
Z4		PINHEAD-1X4

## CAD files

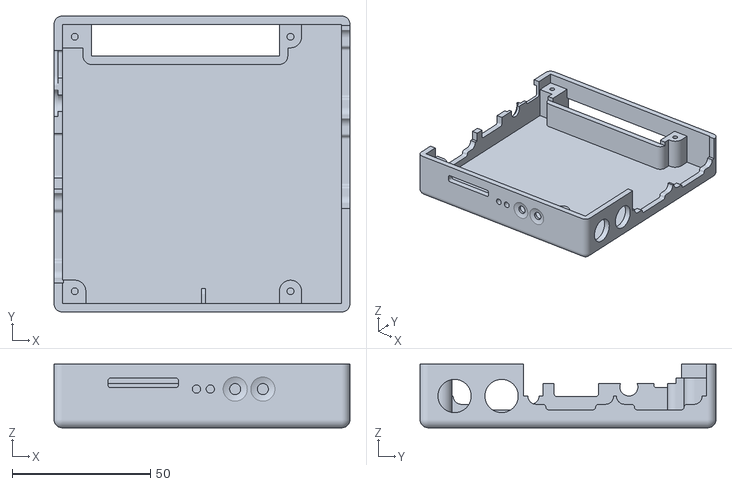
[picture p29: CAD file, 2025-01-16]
v1.9/3D/case/diy-top.stl
107.0 x 107.0 x 23.0

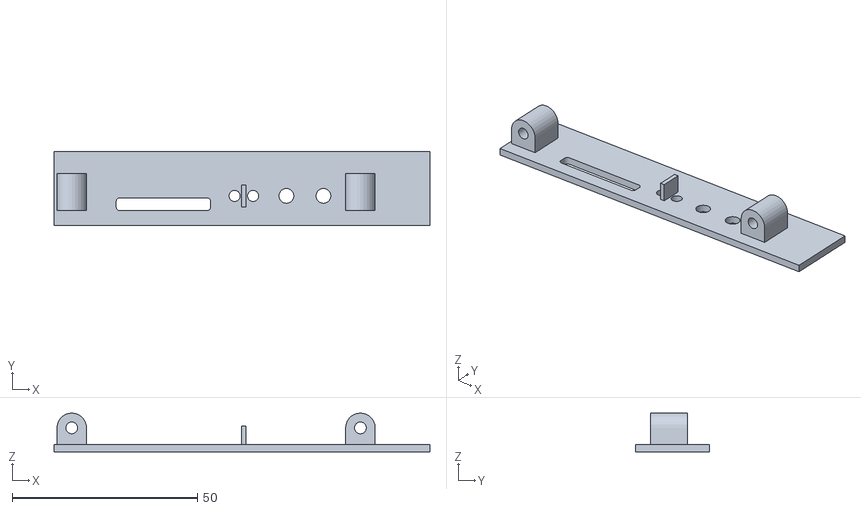
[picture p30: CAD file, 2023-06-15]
v1.9/3D/panel.stl
101.6 x 20.0 x 10.5

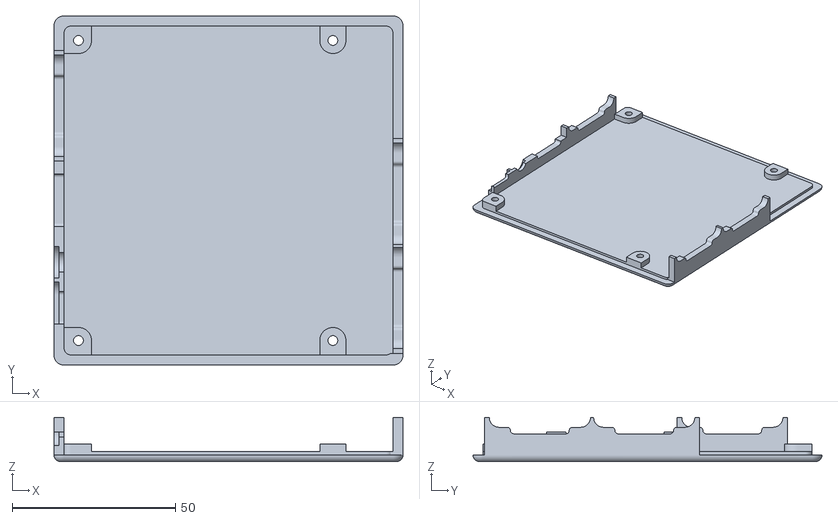
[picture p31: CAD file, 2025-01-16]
v1.9/3D/case/diy-bot.stl
107.0 x 107.0 x 13.5

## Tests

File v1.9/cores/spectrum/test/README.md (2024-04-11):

# spectrum core

- v0.1.x
  - scandoubler fix
  - sound fix

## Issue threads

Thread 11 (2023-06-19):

WHDLoad exit key PrtScr conflicts with amiga(/mikan) core switch resolution PrtScr key

samowitsch, 2023-06-19:
There is a PrtScr key conflict between amiga core and WHDLoad games that also use PrtScr as exit key.
In this case it is not possible to return back to Amiga  Workbench.
Is it possible using F12 for amiga core to switch screen resolution?

samowitsch, 2023-06-21:
Regarding to your comment on elektroda.pl you pointed me to the right direction. thx

ℹ️ The WHDLoad QuitKey can be set accordingly either via the Game Icon -> Icon/Information -> Tool Types -> QuitKey or globally in file S:WHDLoad.prefs.

Links:
http://whdload.de/docs/en/opt.html#QuitKey
http://whdload.de/docs/en/rawkey.html

Examples:
F10    $59
PrtSc  $5d

Closed 2023-06-21.
